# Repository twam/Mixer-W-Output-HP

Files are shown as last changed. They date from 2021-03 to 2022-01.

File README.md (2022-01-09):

Mixer-W-Output-HP
===

This repository is part of the USB audio mixer project described on https://www.twam.info/general/building-a-custom-usb-audio-mixer.

The 'W-Output HP' board is an W-Output compatible head phone amplifier, which can be used on
[W-DAC 4493](https://nihtila.com/2020/02/27/w-dac-4493-very-high-performance-compact-dac/) or
[W-DAC S 4493](https://nihtila.com/2020/12/28/w-dac-s-4493/). It is based on the
[HP Buf](https://nihtila.com/2018/02/04/hp-buf-high-current-buffered-amplifier-board-for-hp-mobo/) by
[Tomi Nihtilä](https://nihtila.com).

### Revision 1

Revision 1 misses two feedback resistors (R35, R36 in latest schematic):

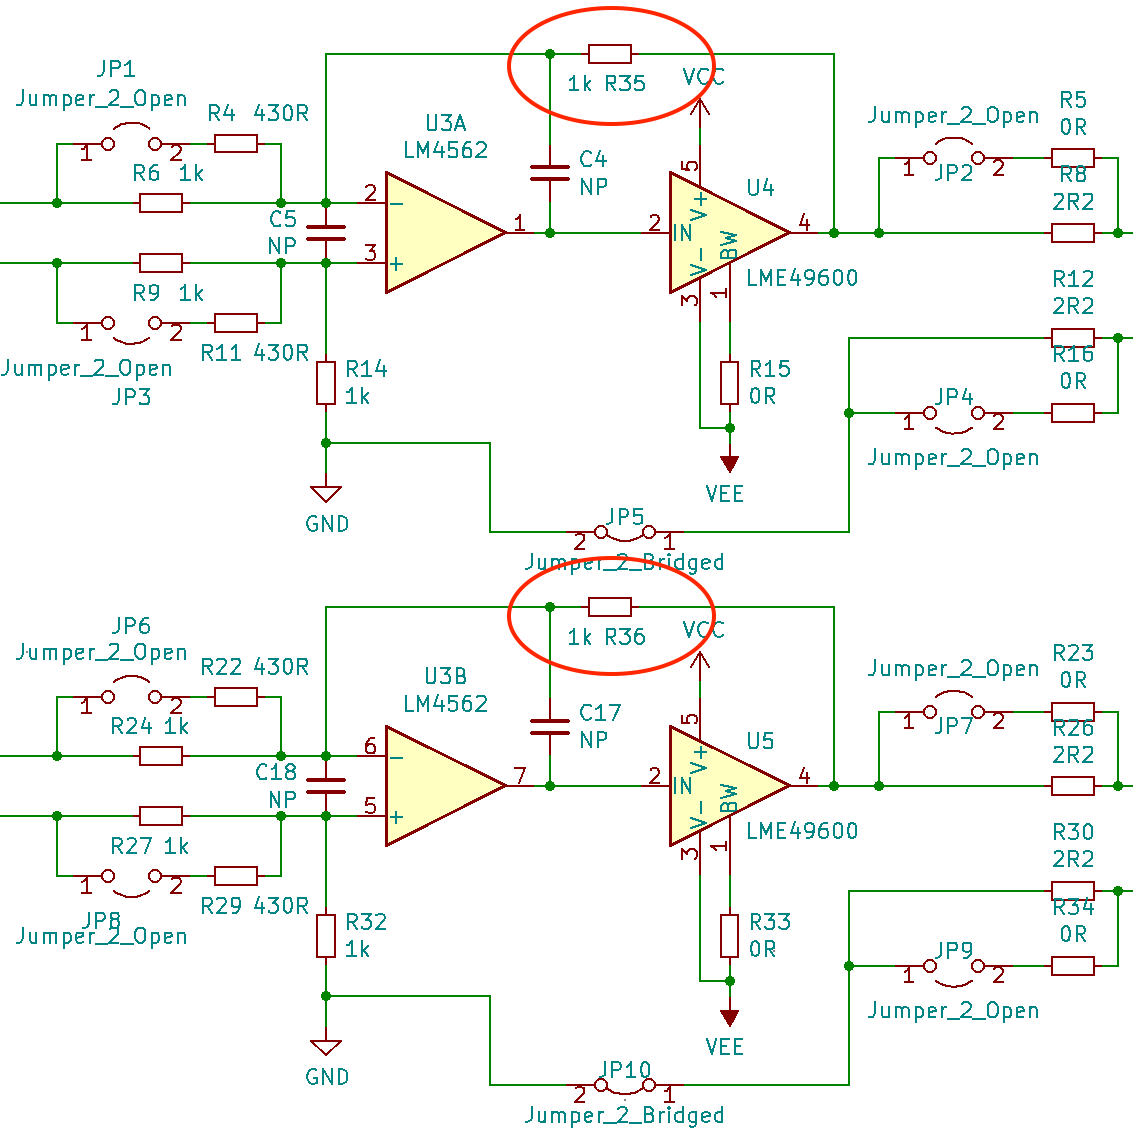
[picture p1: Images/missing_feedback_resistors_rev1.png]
Missing feedback resistors on revision 1 schematic


Those can be easily bodged in with two through hole resistors:

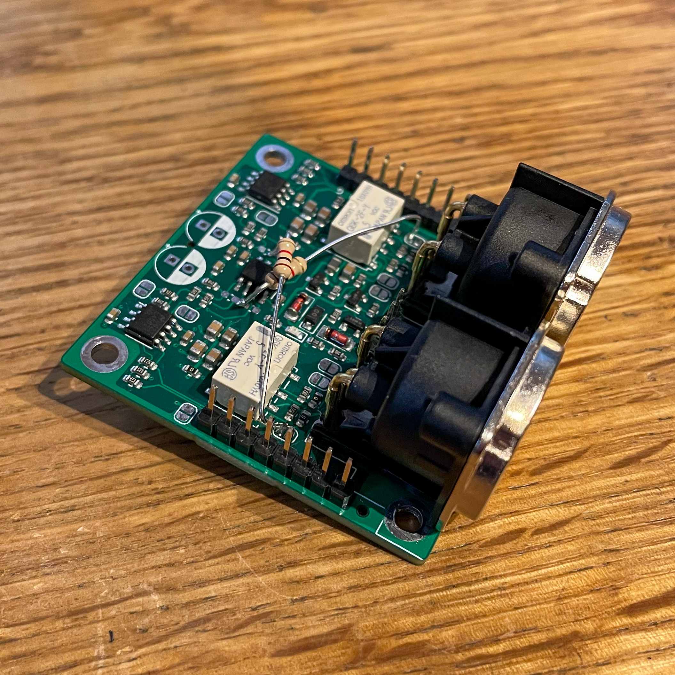
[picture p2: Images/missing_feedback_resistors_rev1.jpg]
missing feedback resistors on revision 1


### JLCPCB

PCBs can be ordered almost fully-assembled from [JLCPCB](https://jlcpcb.com/DDE). Required files are
[W-Output HP_cpl_jlc.csv](Gerber/W-Output%20HP_cpl_jlc.csv), [W-Output HP_bom_jlc.csv](Gerber/W-Output%20HP_bom_jlc.csv) and
[W-Output HP.zip](Gerber/W-Output%20HP.zip). Components missing are
* Two LME49600 on the buttom side of the board (U4, U5)
* Two 100uF electrolytic capacitors (C8, C21)
* Two NC3MBH-1 connectors (J4, J5)
* Two pin headers/pin sockets.

## License

[][cc-by-sa]

This work is licensed under a [Creative Commons Attribution-NonCommercial-ShareAlike 4.0 International License][cc-by-sa].

[][cc-by-sa]

[cc-by-sa]: http://creativecommons.org/licenses/by-nc-sa/4.0/
[cc-by-sa-image]: https://licensebuttons.net/l/by-nc-sa/4.0/88x31.png
[cc-by-sa-shield]: https://img.shields.io/badge/License-CC%20BY--NC--SA%204.0-lightgrey.svg

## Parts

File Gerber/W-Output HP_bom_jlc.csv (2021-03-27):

Comment | Designator | Footprint | LCSC Part #
10u | C1,C7,C6,C3,C2,C20,C19,C16,C15 | C_0805_2012Metric | C15850
100n | C9,C12,C10,C13,C11,C14,C22,C23 | C_0603_1608Metric | C14663
LL4148 | D1,D4 | D_MiniMELF | C9808
red | D2 | LED_0603_1608Metric | C2286
MMSZ4696 | D3 | D_SOD-123 | C93559
G6K-2 | K1,K2 | Relay_DPDT_Omron_G6K-2F-Y | C47190
600R/100M | L1 | L_0805_2012Metric | C1017
MMBT3906 | Q1 | SOT-23 | C53444
MMBT3904 | Q2,Q3 | SOT-23 | C81464
4k7 | R1,R19 | R_0603_1608Metric | C23162
0R | R2,R15,R5,R16,R33,R23,R34 | R_0603_1608Metric | C21189
10k | R3,R20,R18,R21 | R_0603_1608Metric | C25804
430R | R4,R11,R22,R29 | R_0603_1608Metric | C23170
47k | R7,R13,R25,R31 | R_0603_1608Metric | C25819
2R2 | R8,R26,R30,R12 | R_0603_1608Metric | C22939
2M2 | R10,R28 | R_0603_1608Metric | C22938
1k | R17,R6,R9,R14,R24,R27,R32 | R_0603_1608Metric | C21190
LM4562 | U1,U2,U3 | SOIC-8_3.9x4.9mm_P1.27mm | C57367

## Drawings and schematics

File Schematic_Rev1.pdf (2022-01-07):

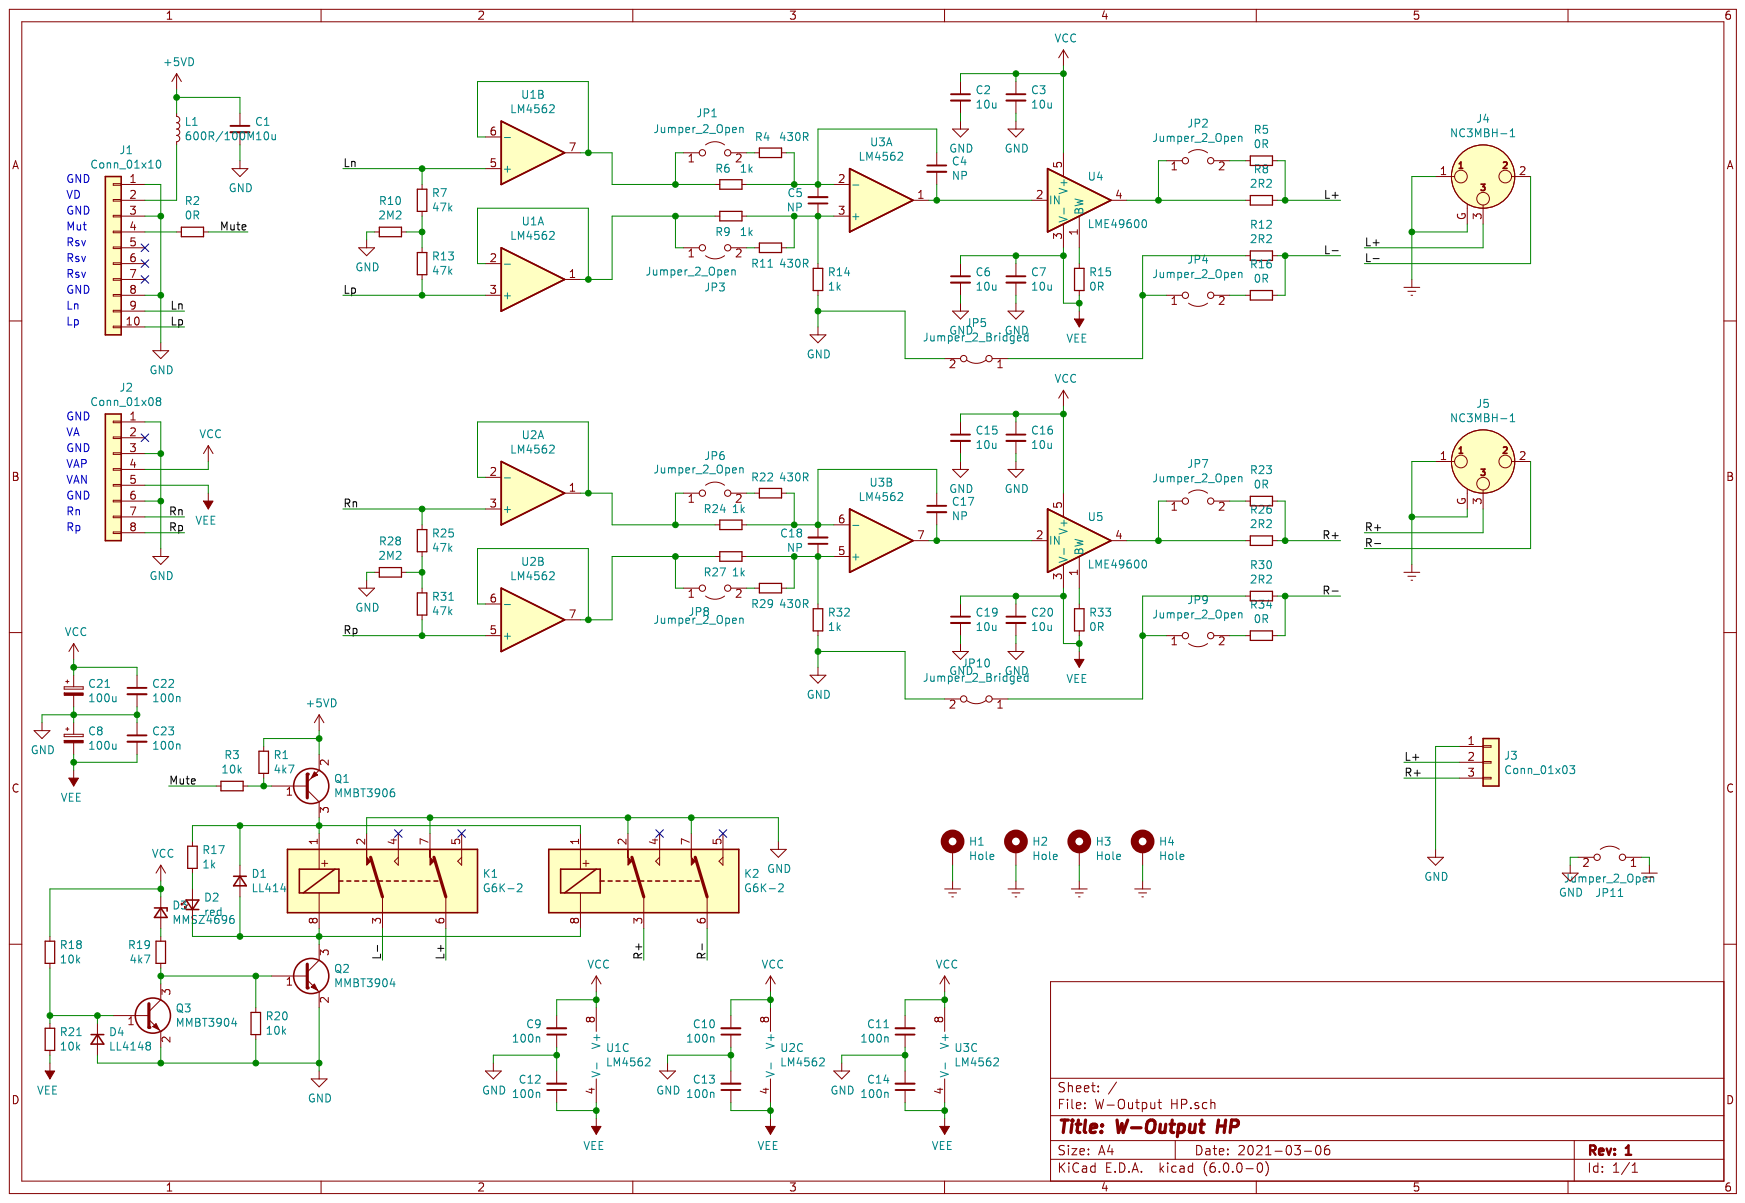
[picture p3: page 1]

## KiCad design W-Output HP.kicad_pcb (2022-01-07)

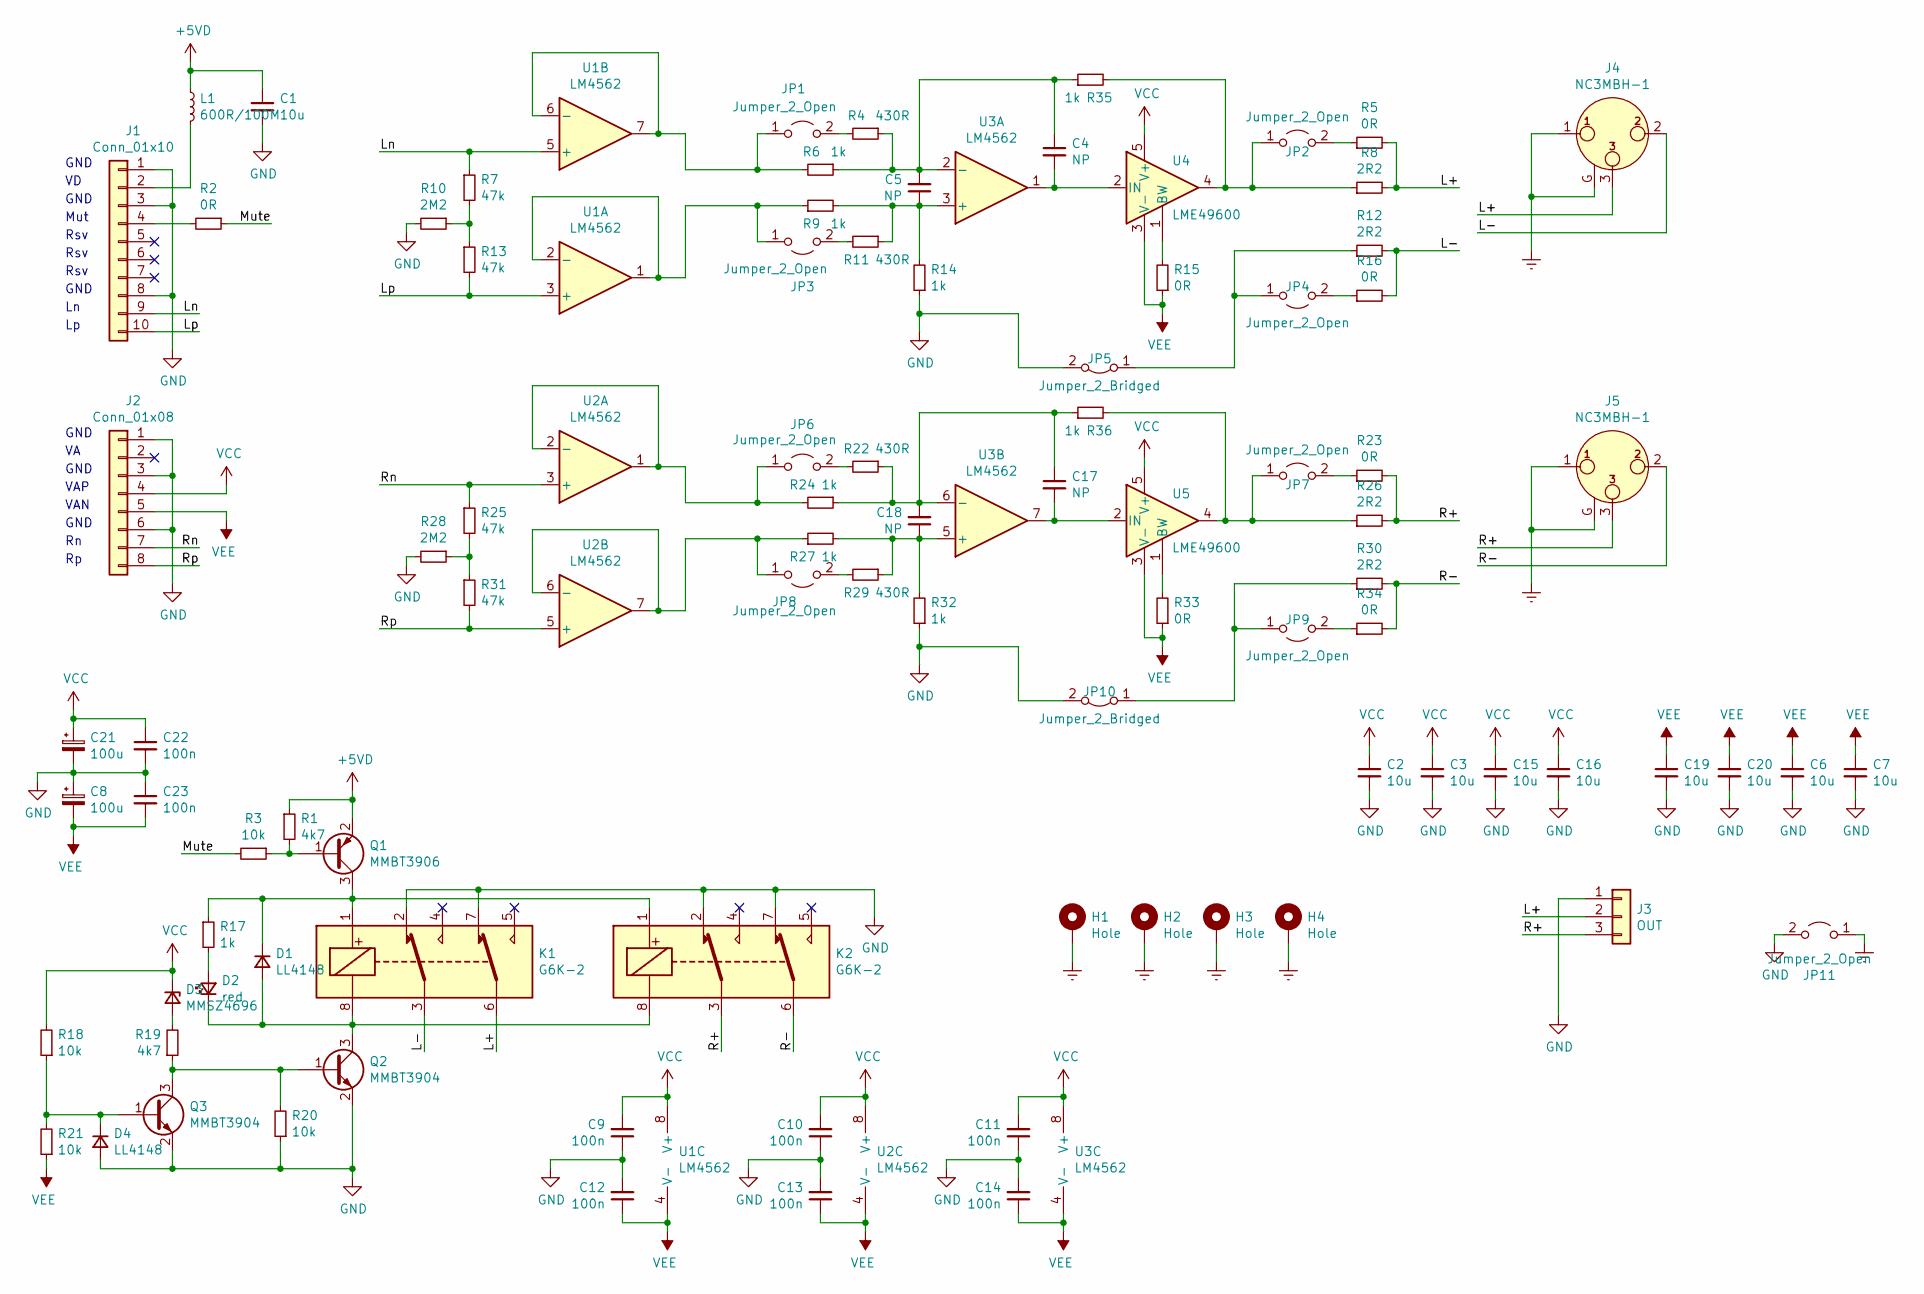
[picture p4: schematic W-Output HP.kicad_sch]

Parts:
C1, C2, C3, C6, C7, C15, C16, C19, C20: 10u; C_0805_2012Metric; LCSC C15850
C4, C5, C17, C18: NP; C_0603_1608Metric
C8, C21: 100u; CP_Radial_D6.3mm_P2.50mm
C9, C10, C11, C12, C13, C14, C22, C23: 100n; C_0603_1608Metric; LCSC C14663
D1, D4: LL4148; D_MiniMELF; LCSC C9808
D2: red; LED_0603_1608Metric; LCSC C2286
D3: MMSZ4696; D_SOD-123; LCSC C93559
H1, H2, H3, H4: Hole; MountingHole_3.2mm_M3_DIN965_Pad
J1: Conn_01x10; PinSocket_1x10_P2.54mm_Vertical
J2: Conn_01x08; PinSocket_1x08_P2.54mm_Vertical
J3: OUT; PinHeader_1x03_P2.54mm_Vertical
J4, J5: NC3MBH-1; Jack_XLR_Neutrik_NC3MBH_Horizontal
JP1, JP2, JP3, JP4, JP6, JP7, JP8, JP9, JP11: Jumper_2_Open; SolderJumper-2_P1.3mm_Open_RoundedPad1.0x1.5mm
JP5, JP10: Jumper_2_Bridged; SolderJumper-2_P1.3mm_Open_RoundedPad1.0x1.5mm
K1, K2: G6K-2; Relay_DPDT_Omron_G6K-2F-Y; LCSC C47190
L1: 600R/100M; L_0805_2012Metric; LCSC C1017
Q1: MMBT3906; SOT-23; LCSC C53444
Q2, Q3: MMBT3904; SOT-23; LCSC C81464
R1, R19: 4k7; R_0603_1608Metric; LCSC C23162
R2, R5, R15, R16, R23, R33, R34: 0R; R_0603_1608Metric; LCSC C21189
R3, R18, R20, R21: 10k; R_0603_1608Metric; LCSC C25804
R4, R11, R22, R29: 430R; R_0603_1608Metric; LCSC C23170
R6, R9, R14, R17, R24, R27, R32, R35, R36: 1k; R_0603_1608Metric; LCSC C21190
R7, R13, R25, R31: 47k; R_0603_1608Metric; LCSC C25819
R8, R12, R26, R30: 2R2; R_0603_1608Metric; LCSC C22939
R10, R28: 2M2; R_0603_1608Metric; LCSC C22938
U1, U2, U3: LM4562; SOIC-8_3.9x4.9mm_P1.27mm; LCSC C57367
U4, U5: LME49600; TO-263-5_TabPin3

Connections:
+5VD: C1.1, L1.1, Q1.2 (E), R1.1
/L+: J3.2, J4.3, K1.6, R5.2, R8.2
/L-: J4.2, K1.3, R12.2, R16.2
/Ln: J1.9, R7.1, U1.5 (+)
/Lp: J1.10, R13.2, U1.3 (+)
/Mute: R2.1, R3.2
/R+: J3.3, J5.3, K2.3, R23.2, R26.2
/R-: J5.2, K2.6, R30.2, R34.2
/Rn: J2.7, R25.1, U2.3 (+)
/Rp: J2.8, R31.2, U2.5 (+)
Earth: H1.1, H2.1, H3.1, H4.1, J4.1, J4.G, J5.1, J5.G, JP11.1 (A)
GND: C1.2, C2.2, C3.2, C6.2, C7.2, C8.1, C9.1, C10.1, C11.1, C12.2, C13.2, C14.2, C15.2, C16.2, C19.2, C20.2, C21.2, C22.2, C23.1, D4.2 (A), J1.1, J1.3, J1.8, J2.1, J2.3, J2.6, J3.1, JP5.2 (B), JP10.2 (B), JP11.2 (B), K1.2, K1.7, K2.2, K2.7, Q2.2 (E), Q3.2 (E), R10.2, R14.1, R20.1, R28.2, R32.1
unnamed: C4.1, C5.2, R4.1, R6.1, R35.1, U3.2 (-)
unnamed: C4.2, U3.1, U4.2 (IN)
unnamed: C5.1, R9.2, R11.1, R14.2, U3.3 (+)
unnamed: C17.1, C18.2, R22.1, R24.1, R36.1, U3.6 (-)
unnamed: C17.2, U3.7, U5.2 (IN)
unnamed: C18.1, R27.2, R29.1, R32.2, U3.5 (+)
unnamed: D1.1 (K), K1.1, K2.1, Q1.3 (C), R17.1
unnamed: D1.2 (A), D2.1 (K), K1.8, K2.8, Q2.3 (C)
unnamed: D2.2 (A), R17.2
unnamed: D3.2 (A), R19.2
unnamed: D4.1 (K), Q3.1 (B), R18.1, R21.2
unnamed: J1.2, L1.2
unnamed: J1.4, R2.2
unnamed: JP1.1 (A), R6.2, U1.6 (-), U1.7
unnamed: JP1.2 (B), R4.2
unnamed: JP2.1 (A), R8.1, R35.2, U4.4
unnamed: JP2.2 (B), R5.1
unnamed: JP3.1 (A), R9.1, U1.1, U1.2 (-)
unnamed: JP3.2 (B), R11.2
unnamed: JP4.1 (A), JP5.1 (A), R12.1
unnamed: JP4.2 (B), R16.1
unnamed: JP6.1 (A), R24.2, U2.1, U2.2 (-)
unnamed: JP6.2 (B), R22.2
unnamed: JP7.1 (A), R26.1, R36.2, U5.4
unnamed: JP7.2 (B), R23.1
unnamed: JP8.1 (A), R27.1, U2.6 (-), U2.7
unnamed: JP8.2 (B), R29.2
unnamed: JP9.2 (B), R34.1
unnamed: JP9.1 (A), JP10.1 (A), R30.1
unnamed: Q1.1 (B), R1.2, R3.1
unnamed: Q2.1 (B), Q3.3 (C), R19.1, R20.2
unnamed: R7.2, R10.1, R13.1
unnamed: R15.2, U4.1 (BW)
unnamed: R25.2, R28.1, R31.1
unnamed: R33.2, U5.1 (BW)
VCC: C2.1, C3.1, C9.2, C10.2, C11.2, C15.1, C16.1, C21.1, C22.1, D3.1 (K), J2.4, R18.2, U1.8 (V+), U2.8 (V+), U3.8 (V+), U4.5 (V+), U5.5 (V+)
VEE: C6.1, C7.1, C8.2, C12.1, C13.1, C14.1, C19.1, C20.1, C23.2, J2.5, R15.1, R21.1, R33.1, U1.4 (V-), U2.4 (V-), U3.4 (V-), U4.3 (V-), U5.3 (V-)

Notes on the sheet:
Mut
GND
Rsv
VAN
VAP

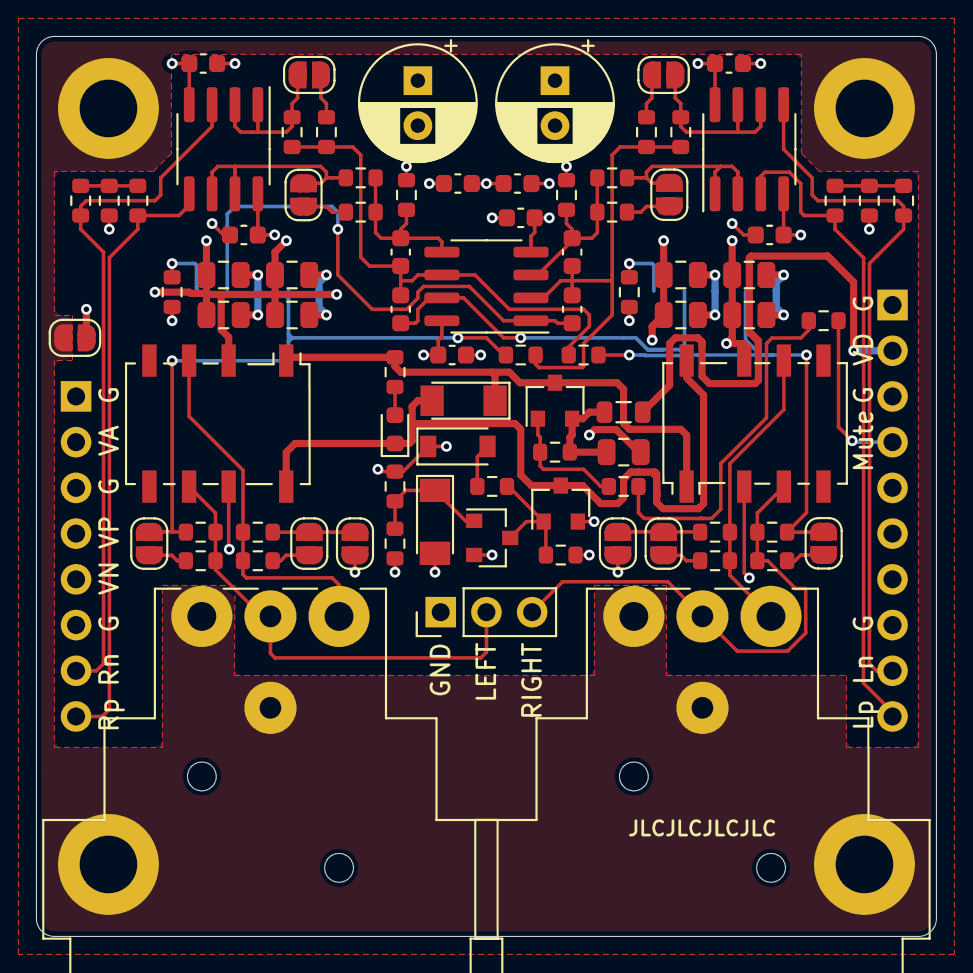
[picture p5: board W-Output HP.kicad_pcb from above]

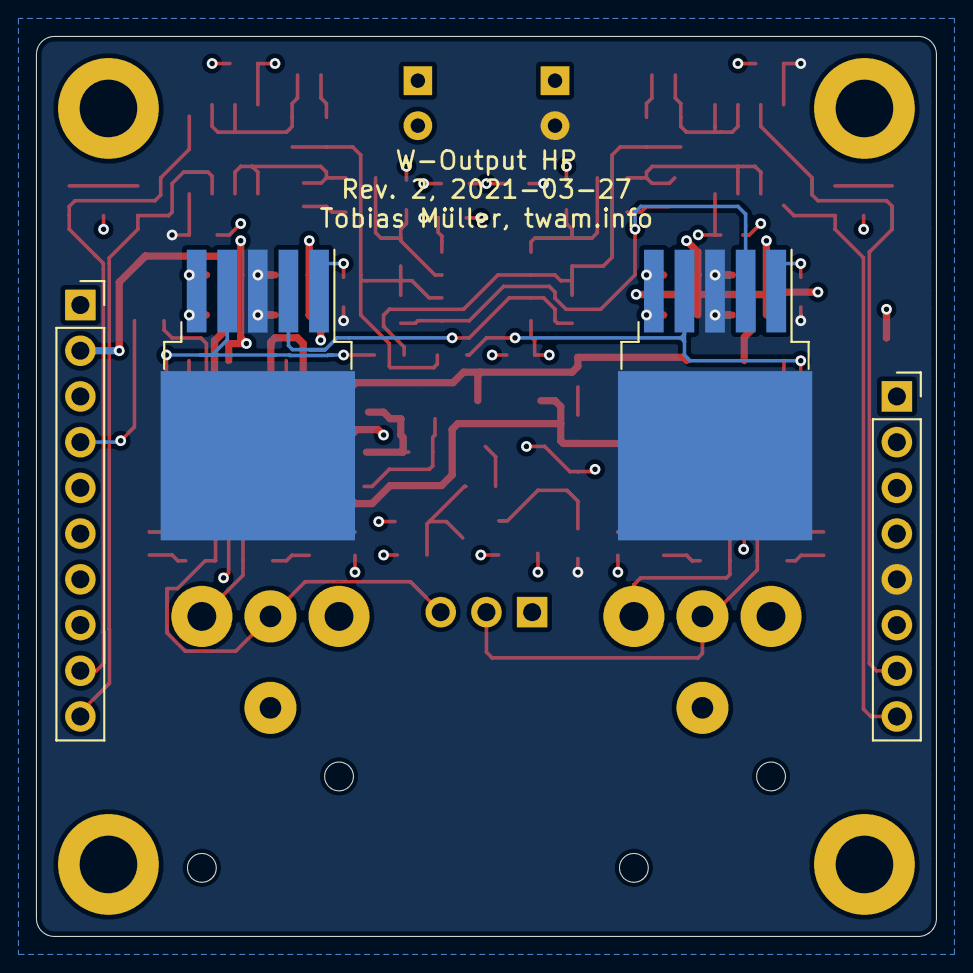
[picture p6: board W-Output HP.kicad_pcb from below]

Board: 4 copper layers, 50.0 x 50.0 mm, 94 parts (4 on the bottom side), 49 nets.

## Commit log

2021-03-27 Initial commit. Rev 1.
    [W-Output HP-B_Cu.gbr, W-Output HP-B_Mask.gbr, W-Output HP-B_Paste.gbr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]
2022-01-07 Add missing feedback resistor
    [W-Output HP.kicad_pcb, W-Output HP.sch]
2022-01-07 Update to KiCad 6
    [W-Output HP.kicad_sch, W-Output HP.sch]
2022-01-07 Move JLCPCB files to Gerber
    [W-Output HP_bom_jlc.csv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]
2022-01-07 Add Schematic Rev. 1
